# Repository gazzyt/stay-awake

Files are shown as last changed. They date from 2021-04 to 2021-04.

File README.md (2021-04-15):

A simple firmware for keeping PCs awake. In a corporate environment we often have to put up with a managed desktop which is set to lock after a short period of inactivity and we are not able to change that configuration. Well you could build a robot to wiggle your mouse every so often or you could build one of these devices which presents itself to the host as a USB mouse and every minute it moves that mouse 1 pixel left and then right again. You'd have to look very carefully to notice yourself but it's enough to keep the PC thinking you are active!

Hardware
========
Design files are shown in the hardware folder and were drawn with KiCad version (5.1.9)-1. The printable folder contains the following:
* a schematic PDF
* a pcb design PDF
* a PDF plot in mirrored negative which I used to create the PCB with negative photo-resist film

Firmware
========
The firmware is built on the fantastic [v-usb](https://github.com/obdev/v-usb) USB driver which provides USB capabilities to AVR devices that lack USB hardware. I have modified one of their samples.

The firmware is built with Microchip Studio 7.0.2542.

Programming
-----------
Set fuses as shown
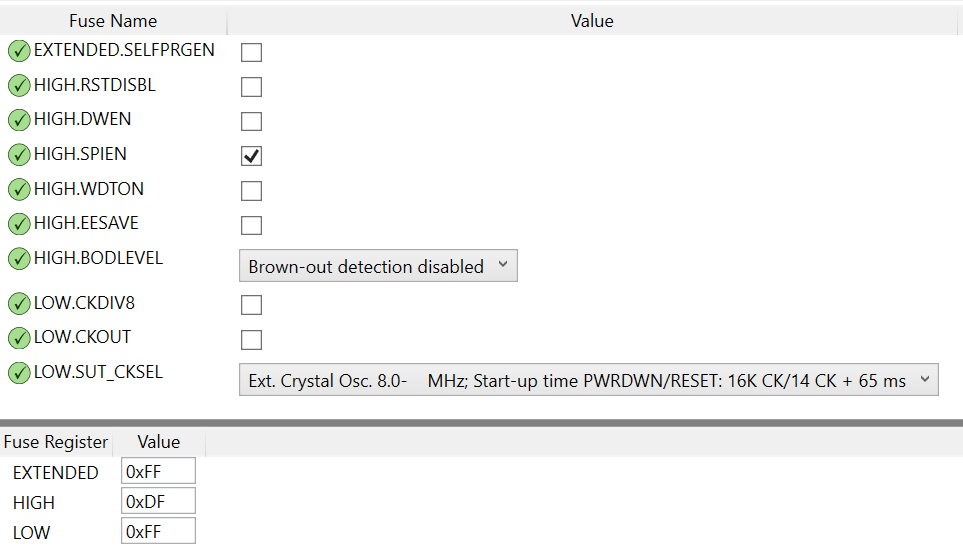
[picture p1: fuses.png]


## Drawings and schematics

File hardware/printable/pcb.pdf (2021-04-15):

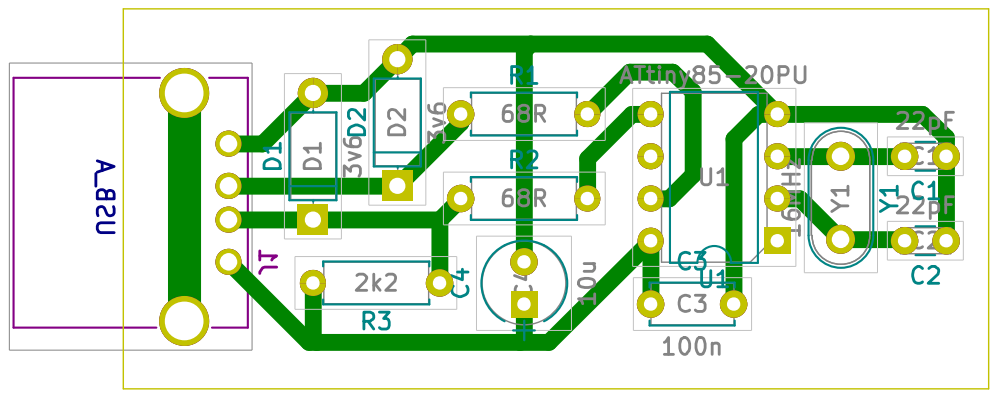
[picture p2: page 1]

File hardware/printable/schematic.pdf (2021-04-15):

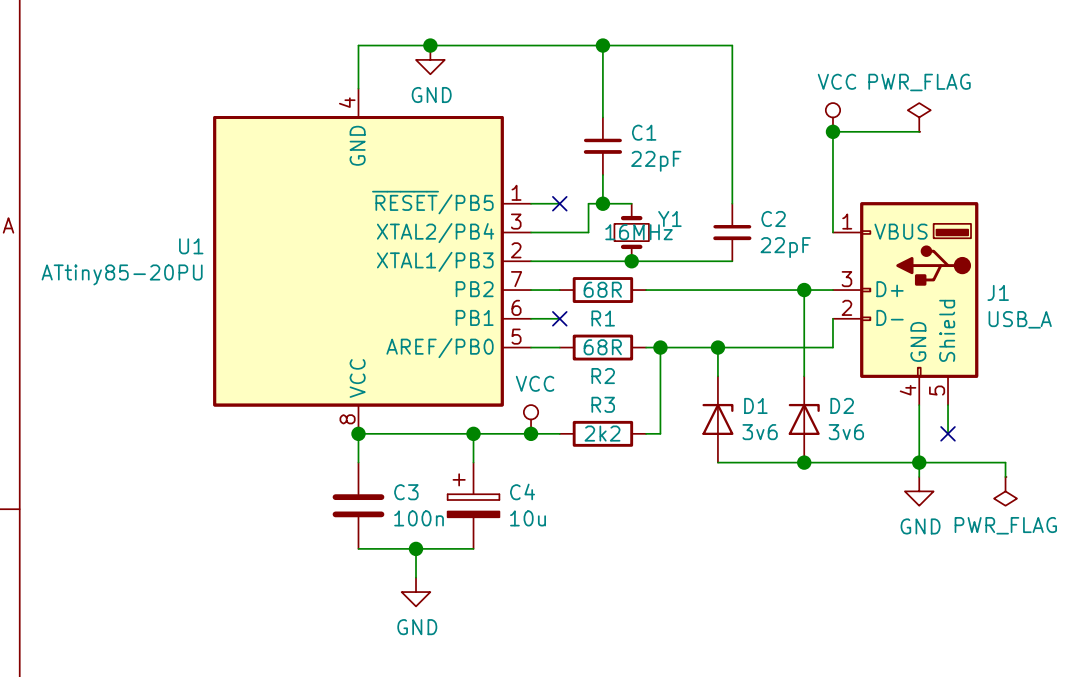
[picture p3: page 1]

File: stay-awake-v1.sch Sheet: /
Id: 1/1 Title:

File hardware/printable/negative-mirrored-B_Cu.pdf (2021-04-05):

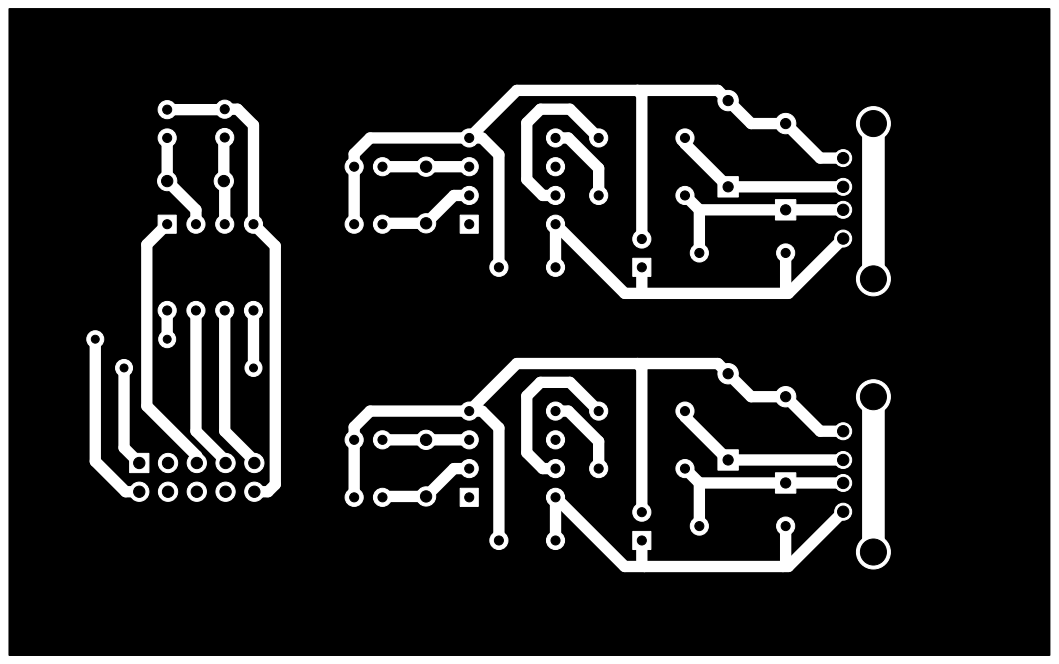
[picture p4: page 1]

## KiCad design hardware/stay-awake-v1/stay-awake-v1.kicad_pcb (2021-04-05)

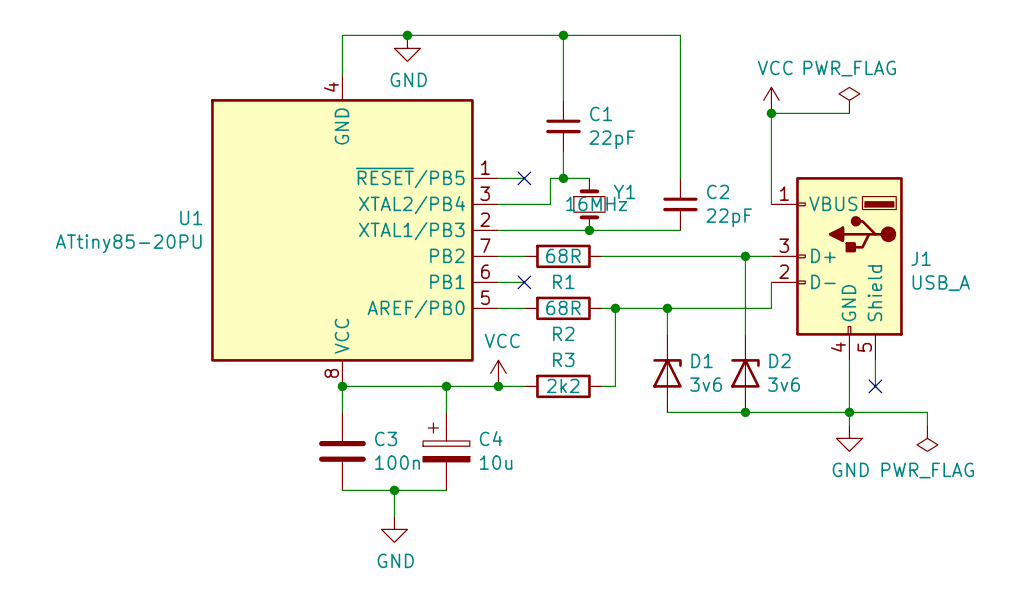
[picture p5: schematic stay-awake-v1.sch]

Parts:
C1, C2: 22pF; C_Disc_D3.0mm_W1.6mm_P2.50mm
C3: 100n; C_Disc_D5.0mm_W2.5mm_P5.00mm
C4: 10u; CP_Radial_Tantal_D5.0mm_P2.50mm
D1, D2: 3v6; D_A-405_P7.62mm_Horizontal
J1: USB_A
R1, R2: 68R; R_Axial_DIN0207_L6.3mm_D2.5mm_P7.62mm_Horizontal
R3: 2k2; R_Axial_DIN0207_L6.3mm_D2.5mm_P7.62mm_Horizontal
U1: ATtiny85-20PU; DIP-8_W7.62mm
Y1: 16MHz; Resonator-2pin_w8.0mm_h3.5mm

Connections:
GND: C1.1, C2.1, C3.2, C4.2, D1.2 (A), D2.2 (A), J1.4 (GND), U1.4 (GND)
unnamed: C1.2, U1.3 (XTAL2/PB4), Y1.1
unnamed: C2.2, U1.2 (XTAL1/PB3), Y1.2
unnamed: D1.1 (K), J1.2 (D-), R2.1, R3.1
unnamed: D2.1 (K), J1.3 (D+), R1.1
unnamed: R1.2, U1.7 (PB2)
unnamed: R2.2, U1.5 (AREF/PB0)
VCC: C3.1, C4.1, J1.1 (VBUS), R3.2, U1.8 (VCC)

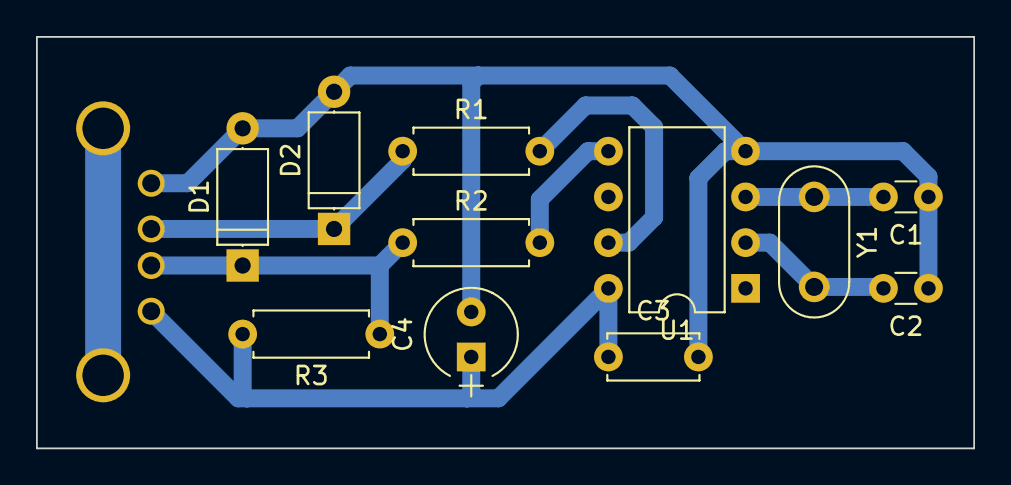
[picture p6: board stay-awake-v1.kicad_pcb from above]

Board: 2 copper layers, 52.1 x 22.9 mm, 12 parts (1 on the bottom side), 8 nets.

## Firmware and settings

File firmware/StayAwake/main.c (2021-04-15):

/* Name: main.c
 * Project: hid-mouse, a very simple HID example
 * Author: Christian Starkjohann
 * Creation Date: 2008-04-07
 * Tabsize: 4
 * Copyright: (c) 2008 by OBJECTIVE DEVELOPMENT Software GmbH
 * License: GNU GPL v2 (see License.txt), GNU GPL v3 or proprietary (CommercialLicense.txt)
 */

/*
This example should run on most AVRs with only little changes. No special
hardware resources except INT0 are used. You may have to change usbconfig.h for
different I/O pins for USB. Please note that USB D+ must be the INT0 pin, or
at least be connected to INT0 as well.

We use VID/PID 0x046D/0xC00E which is taken from a Logitech mouse. Don't
publish any hardware using these IDs! This is for demonstration only!
*/

#include <avr/io.h>
#include <avr/wdt.h>
#include <avr/interrupt.h>  /* for sei() */

#include <avr/pgmspace.h>   /* required by usbdrv.h */
#include "usbdrv.h"
#include "oddebug.h"        /* This is also an example for using debug macros */
#include <util/delay.h>     /* for _delay_ms() */

/* ------------------------------------------------------------------------- */
/* ----------------------------- USB interface ----------------------------- */
/* ------------------------------------------------------------------------- */

PROGMEM const char usbHidReportDescriptor[52] = { /* USB report descriptor, size must match usbconfig.h */
    0x05, 0x01,                    // USAGE_PAGE (Generic Desktop)
    0x09, 0x02,                    // USAGE (Mouse)
    0xa1, 0x01,                    // COLLECTION (Application)
    0x09, 0x01,                    //   USAGE (Pointer)
    0xA1, 0x00,                    //   COLLECTION (Physical)
    0x05, 0x09,                    //     USAGE_PAGE (Button)
    0x19, 0x01,                    //     USAGE_MINIMUM
    0x29, 0x03,                    //     USAGE_MAXIMUM
    0x15, 0x00,                    //     LOGICAL_MINIMUM (0)
    0x25, 0x01,                    //     LOGICAL_MAXIMUM (1)
    0x95, 0x03,                    //     REPORT_COUNT (3)
    0x75, 0x01,                    //     REPORT_SIZE (1)
    0x81, 0x02,                    //     INPUT (Data,Var,Abs)
    0x95, 0x01,                    //     REPORT_COUNT (1)
    0x75, 0x05,                    //     REPORT_SIZE (5)
    0x81, 0x03,                    //     INPUT (Const,Var,Abs)
    0x05, 0x01,                    //     USAGE_PAGE (Generic Desktop)
    0x09, 0x30,                    //     USAGE (X)
    0x09, 0x31,                    //     USAGE (Y)
    0x09, 0x38,                    //     USAGE (Wheel)
    0x15, 0x81,                    //     LOGICAL_MINIMUM (-127)
    0x25, 0x7F,                    //     LOGICAL_MAXIMUM (127)
    0x75, 0x08,                    //     REPORT_SIZE (8)
    0x95, 0x03,                    //     REPORT_COUNT (3)
    0x81, 0x06,                    //     INPUT (Data,Var,Rel)
    0xC0,                          //   END_COLLECTION
    0xC0,                          // END COLLECTION
};
/* This is the same report descriptor as seen in a Logitech mouse. The data
 * described by this descriptor consists of 4 bytes:
 *      .  .  .  .  . B2 B1 B0 .... one byte with mouse button states
 *     X7 X6 X5 X4 X3 X2 X1 X0 .... 8 bit signed relative coordinate x
 *     Y7 Y6 Y5 Y4 Y3 Y2 Y1 Y0 .... 8 bit signed relative coordinate y
 *     W7 W6 W5 W4 W3 W2 W1 W0 .... 8 bit signed relative coordinate wheel
 */
typedef struct{
    uchar   buttonMask;
    char    dx;
    char    dy;
    char    dWheel;
}report_t;

static report_t reportBuffer;
static uchar    idleRate;   /* repeat rate for keyboards, never used for mice */


#define CYCLES_BETWEEN_JIGGLES (10*60)

static void jiggleMouse()
{
	static unsigned int cycle = 0;

	if (cycle > CYCLES_BETWEEN_JIGGLES)
	{
		cycle = 0;
	}

	if (cycle == 0)
	{
		reportBuffer.dx = 1;
	}
	else if (cycle == 1)
	{
		reportBuffer.dx = -1;
	}
	else
	{
		reportBuffer.dx = 0;
	}

	++cycle;
}

/* ------------------------------------------------------------------------- */

usbMsgLen_t usbFunctionSetup(uchar data[8])
{
usbRequest_t    *rq = (void *)data;

    /* The following requests are never used. But since they are required by
     * the specification, we implement them in this example.
     */
    if((rq->bmRequestType & USBRQ_TYPE_MASK) == USBRQ_TYPE_CLASS){    /* class request type */
        DBG1(0x50, &rq->bRequest, 1);   /* debug output: print our request */
        if(rq->bRequest == USBRQ_HID_GET_REPORT){  /* wValue: ReportType (highbyte), ReportID (lowbyte) */
            /* we only have one report type, so don't look at wValue */
            usbMsgPtr = (void *)&reportBuffer;
            return sizeof(reportBuffer);
        }else if(rq->bRequest == USBRQ_HID_GET_IDLE){
            usbMsgPtr = &idleRate;
            return 1;
        }else if(rq->bRequest == USBRQ_HID_SET_IDLE){
            idleRate = rq->wValue.bytes[1];
        }
    }else{
        /* no vendor specific requests implemented */
    }
    return 0;   /* default for not implemented requests: return no data back to host */
}

/* ------------------------------------------------------------------------- */

int __attribute__((noreturn)) main(void)
{
uchar   i;

    wdt_enable(WDTO_1S);
    /* If you don't use the watchdog, replace the call above with a wdt_disable().
     * On newer devices, the status of the watchdog (on/off, period) is PRESERVED
     * OVER RESET!
     */
    /* RESET status: all port bits are inputs without pull-up.
     * That's the way we need D+ and D-. Therefore we don't need any
     * additional hardware initialization.
     */
    odDebugInit();
    DBG1(0x00, 0, 0);       /* debug output: main starts */
    usbInit();
    usbDeviceDisconnect();  /* enforce re-enumeration, do this while interrupts are disabled! */
    i = 0;
    while(--i){             /* fake USB disconnect for > 250 ms */
        wdt_reset();
        _delay_ms(1);
    }
    usbDeviceConnect();
    sei();
    DBG1(0x01, 0, 0);       /* debug output: main loop starts */
    for(;;){                /* main event loop */
        DBG1(0x02, 0, 0);   /* debug output: main loop iterates */
        wdt_reset();
        usbPoll();
        if(usbInterruptIsReady()){
            /* called after every poll of the interrupt endpoint */
			jiggleMouse();
            DBG1(0x03, 0, 0);   /* debug output: interrupt report prepared */
            usbSetInterrupt((void *)&reportBuffer, sizeof(reportBuffer));
        }
    }
}

/* ------------------------------------------------------------------------- */

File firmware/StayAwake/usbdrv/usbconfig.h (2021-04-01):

/* Name: usbconfig.h
 * Project: V-USB, virtual USB port for Atmel's(r) AVR(r) microcontrollers
 * Author: Christian Starkjohann
 * Creation Date: 2005-04-01
 * Tabsize: 4
 * Copyright: (c) 2005 by OBJECTIVE DEVELOPMENT Software GmbH
 * License: GNU GPL v2 (see License.txt), GNU GPL v3 or proprietary (CommercialLicense.txt)
 */

#ifndef __usbconfig_h_included__
#define __usbconfig_h_included__

#define F_CPU 16000000

/*
General Description:
This file is an example configuration (with inline documentation) for the USB
driver. It configures V-USB for USB D+ connected to Port D bit 2 (which is
also hardware interrupt 0 on many devices) and USB D- to Port D bit 4. You may
wire the lines to any other port, as long as D+ is also wired to INT0 (or any
other hardware interrupt, as long as it is the highest level interrupt, see
section at the end of this file).
+ To create your own usbconfig.h file, copy this file to your project's
+ firmware source directory) and rename it to "usbconfig.h".
+ Then edit it accordingly.
*/

/* ---------------------------- Hardware Config ---------------------------- */

#define USB_CFG_IOPORTNAME      B
/* This is the port where the USB bus is connected. When you configure it to
 * "B", the registers PORTB, PINB and DDRB will be used.
 */
#define USB_CFG_DMINUS_BIT      0
/* This is the bit number in USB_CFG_IOPORT where the USB D- line is connected.
 * This may be any bit in the port.
 */
#define USB_CFG_DPLUS_BIT       2
/* This is the bit number in USB_CFG_IOPORT where the USB D+ line is connected.
 * This may be any bit in the port. Please note that D+ must also be connected
 * to interrupt pin INT0! [You can also use other interrupts, see section
 * "Optional MCU Description" below, or you can connect D- to the interrupt, as
 * it is required if you use the USB_COUNT_SOF feature. If you use D- for the
 * interrupt, the USB interrupt will also be triggered at Start-Of-Frame
 * markers every millisecond.]
 */
#define USB_CFG_CLOCK_KHZ       (F_CPU/1000)
/* Clock rate of the AVR in kHz. Legal values are 12000, 12800, 15000, 16000,
 * 16500, 18000 and 20000. The 12.8 MHz and 16.5 MHz versions of the code
 * require no crystal, they tolerate +/- 1% deviation from the nominal
 * frequency. All other rates require a precision of 2000 ppm and thus a
 * crystal!
 * Since F_CPU should be defined to your actual clock rate anyway, you should
 * not need to modify this setting.
 */
#define USB_CFG_CHECK_CRC       0
/* Define this to 1 if you want that the driver checks integrity of incoming
 * data packets (CRC checks). CRC checks cost quite a bit of code size and are
 * currently only available for 18 MHz crystal clock. You must choose
 * USB_CFG_CLOCK_KHZ = 18000 if you enable this option.
 */

/* ----------------------- Optional Hardware Config ------------------------ */

/* #define USB_CFG_PULLUP_IOPORTNAME   D */
/* If you connect the 1.5k pullup resistor from D- to a port pin instead of
 * V+, you can connect and disconnect the device from firmware by calling
 * the macros usbDeviceConnect() and usbDeviceDisconnect() (see usbdrv.h).
 * This constant defines the port on which the pullup resistor is connected.
 */
/* #define USB_CFG_PULLUP_BIT          4 */
/* This constant defines the bit number in USB_CFG_PULLUP_IOPORT (defined
 * above) where the 1.5k pullup resistor is connected. See description
 * above for details.
 */

/* --------------------------- Functional Range ---------------------------- */
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

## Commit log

2021-04-01 Initial project - sample copied from SDK
2021-04-01 Add schematic
    [stay-awake-v1.kicad_pcb, stay-awake-v1.sch]
2021-04-05 Add pcb
    [stay-awake-v1.kicad_pcb, stay-awake-v1.sch]
